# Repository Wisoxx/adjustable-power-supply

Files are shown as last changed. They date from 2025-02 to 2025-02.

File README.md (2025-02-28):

# Adjustable Laboratory Power Supply

## Device Overview  
This project focuses on designing and building a laboratory power supply with adjustable output voltage and integrated measurement of both voltage and load current. The device serves as a versatile tool for powering and diagnosing various electronic circuits. Special attention was given to precise voltage regulation, accurate measurements, and stable operation.
s

## Specifications
- **Input Voltage:** 230V AC, 50Hz  
- **Output Voltage Range:** 1.3V – 15V  
- **Maximum Output Current:** 0.5A  
- **Current Measurement Resolution:** 1mA  
- **Control:** Voltage adjustment and parameter reading via computer  
- **Voltage Regulation:** Manual, using a potentiometer  
- **Display:** Voltage measurement shown on a screen  

## Hardware Overview
The circuit consists of multiple sections:
1. **Power Supply and Rectification**  
2. **Microcontroller and User Interface**  
3. **Voltage Level Adjustment**  
4. **Voltage Transmission**  
5. **Voltage Measurement and Noise Suppression**  
6. **Current Measurement via a Series Resistor**

A schematic of the circuit is included in the documentation.

## Circuit Description
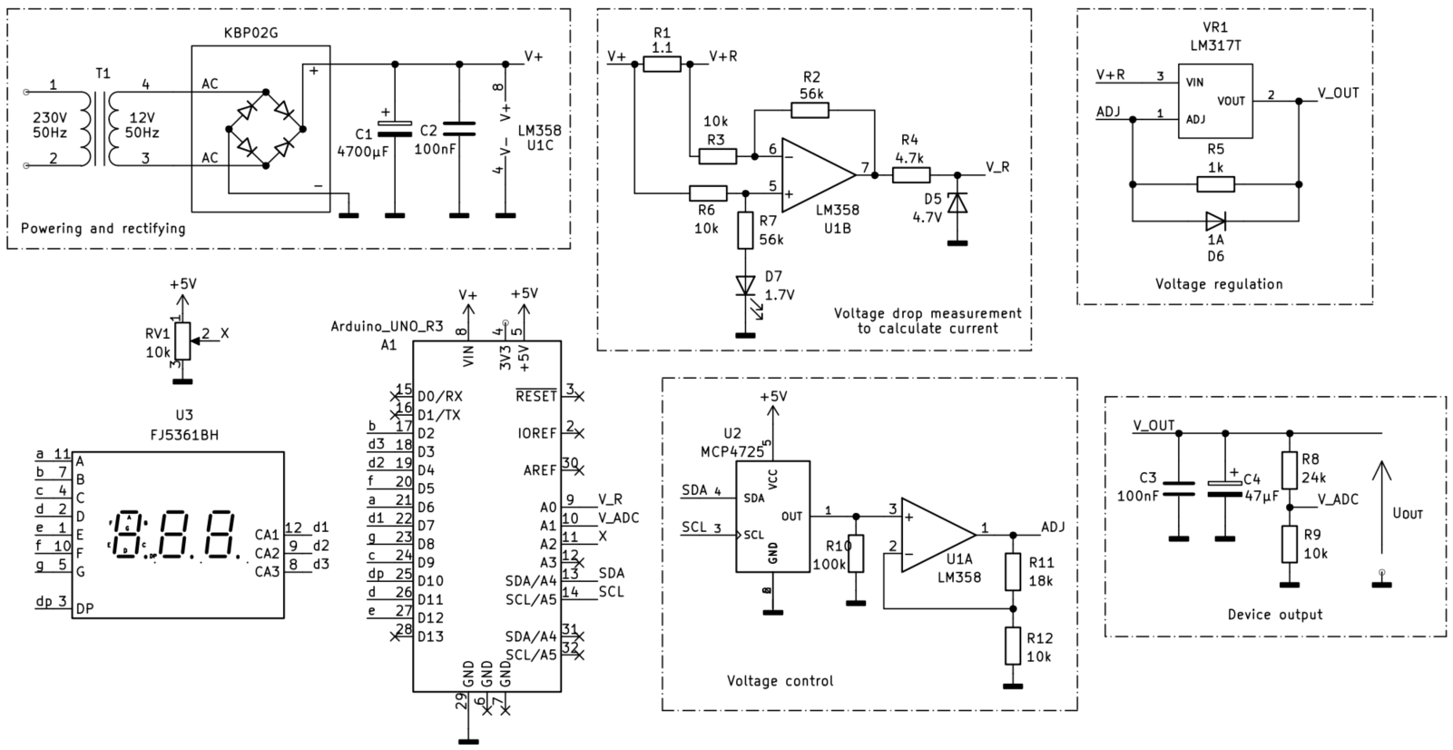
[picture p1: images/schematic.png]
Cicuit Schematic

The power supply uses a **230V to 12V transformer**, followed by a **KBP02G bridge rectifier** for full-wave rectification. A **4700µF capacitor (C1)** smooths voltage fluctuations, and **C2** acts as a decoupling capacitor. The supply voltage powers an **LM358 operational amplifier**, an **Arduino Uno microcontroller**, and other circuit components. 

Voltage regulation is performed using an **LM317T adjustable voltage regulator**, with control signals processed by the microcontroller. A **DAC (Digital-to-Analog Converter)** controlled via **I2C** is used to set the output voltage. A **non-inverting operational amplifier** scales the DAC output to drive the **LM317T**, enabling software-based voltage adjustment.

For **current measurement**, a **series resistor (R1)** is used to determine voltage drop, which is then amplified using a **differential amplifier**. The microcontroller calculates the current using Ohm's Law.

User interaction is facilitated through a **potentiometer (RV1)** for manual voltage adjustment and a **three-digit 7-segment display** for real-time parameter visualization.

## Software Implementation
The Arduino Uno is programmed using **C++** in **Arduino IDE**. The software consists of two main modules:
1. **Main Module:** Reads voltage and current values, processes signals, and communicates with the computer.
2. **Display Module:** Handles the 7-segment display, efficiently updating digits to minimize memory usage.

The software also includes an optional feature to generate **sinusoidal waveforms**, which can be activated by modifying specific code sections.

## Device Views
Below are different perspectives of the assembled device:

### Front View
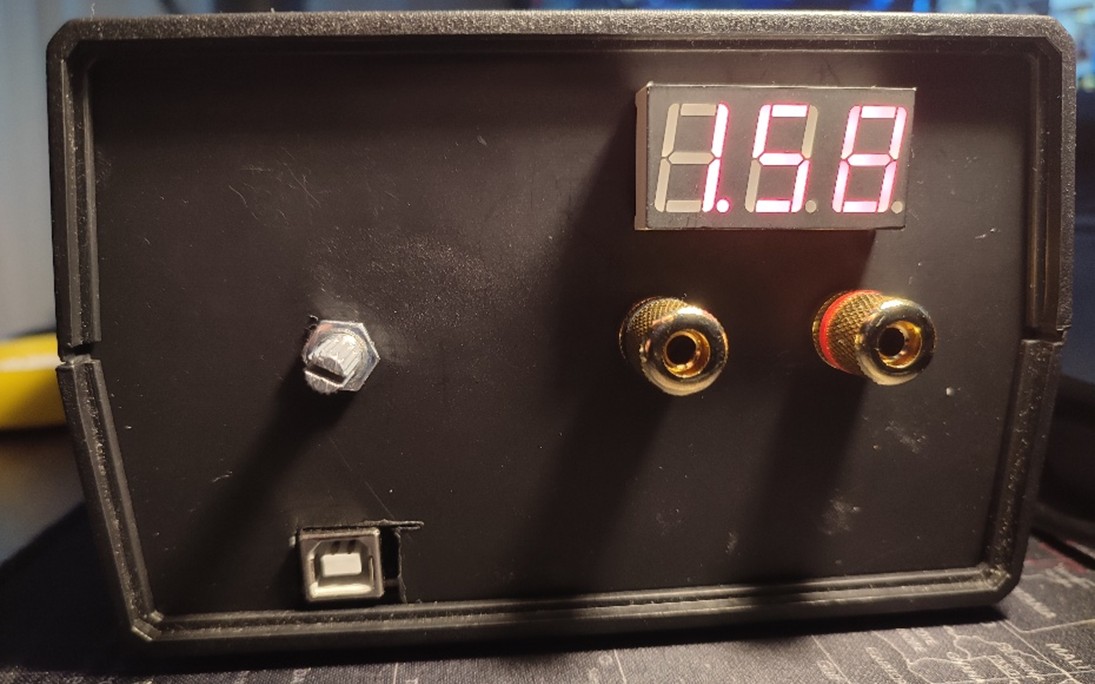
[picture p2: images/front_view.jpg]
Front View


### Back View
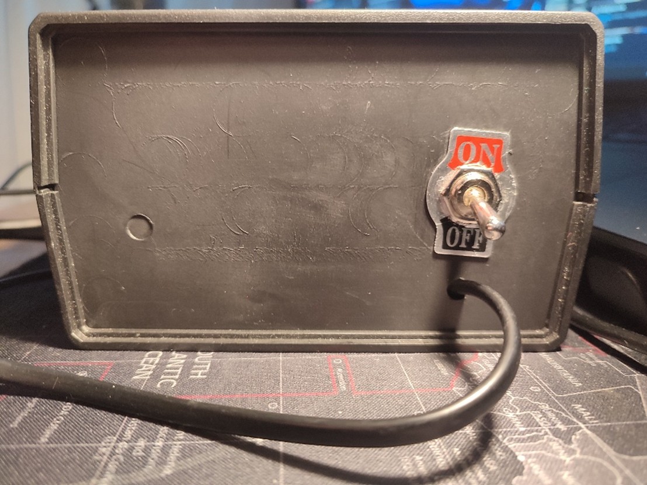
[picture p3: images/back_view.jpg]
Back View


### Internal Components
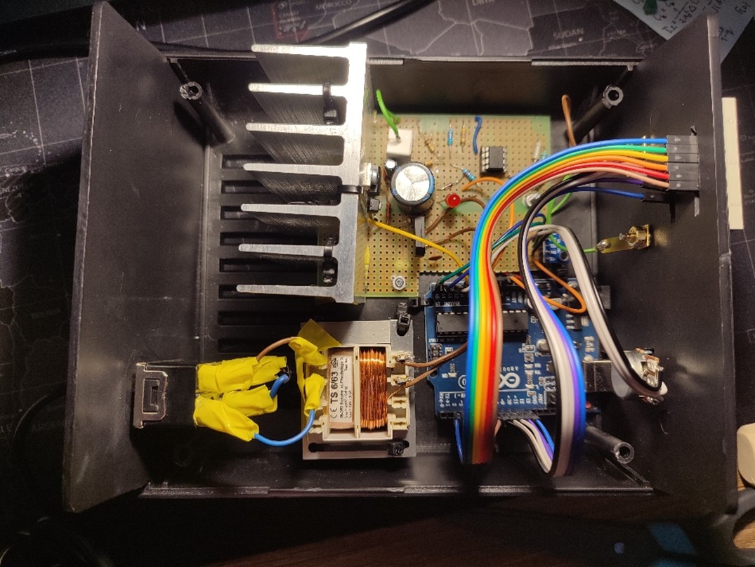
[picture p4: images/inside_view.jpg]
Inside View


### Internal Components
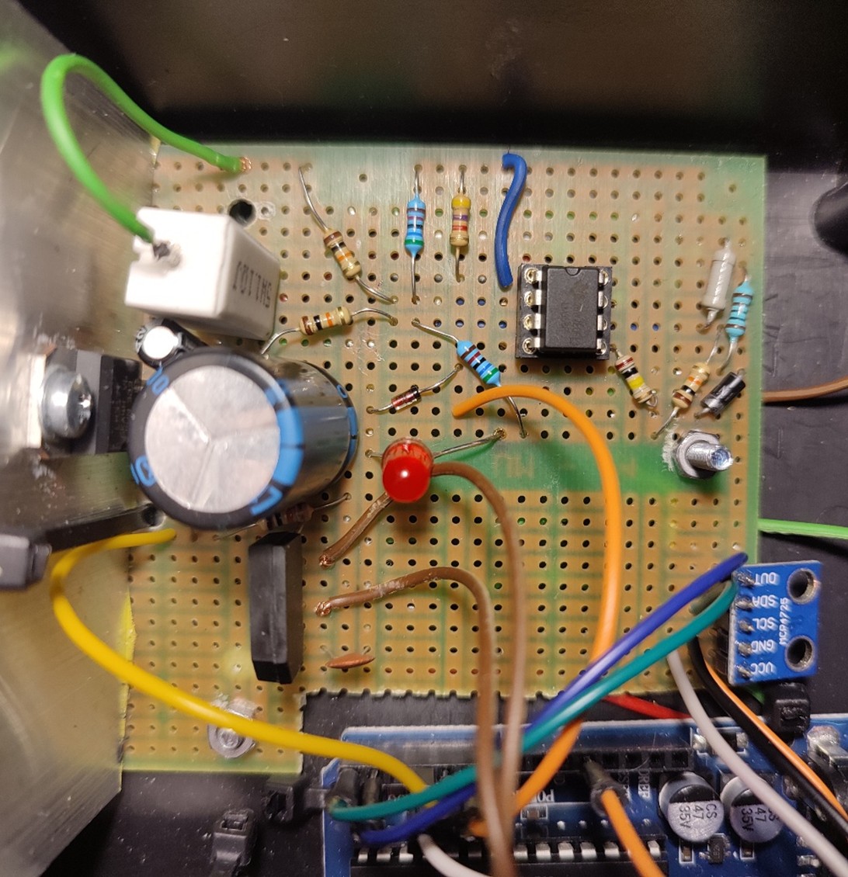
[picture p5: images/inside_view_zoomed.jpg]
Inside View Zoomed


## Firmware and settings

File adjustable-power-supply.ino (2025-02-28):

#include <Wire.h>//Include the Wire library to talk I2C
#include "display.h"
#include <math.h>

//This is the I2C Address of the MCP4725, by default (A0 pulled to GND).
#define MCP4725_ADDR 0x60
//For devices with A0 pulled HIGH, use 0x60
const int i_pin = A0;
const int u_pin = A1;
const int x_pin = A2;
const int size = 100;

int sineWave[size];
int x;
int index = 0;
unsigned long lastSerialUpdate = 0;
const int serialUpdateInterval = 100;
int sample_idx = 0;

void generateSineWave() {
  for (int i = 0; i < size; i++) {
    float angle = (2.0 * M_PI * i) / size; // Convert index to angle
    float sineValue = (sin(angle) + 1.0) / 2.0;  // Normalize from -1..1 to 0..1
    sineWave[i] = (int)(sineValue * 4095); // Scale to 12-bit DAC range (0-4095)
  }
}

void setup()
{
  setupDisplay();
  Wire.begin();
  Serial.begin(115200);
  generateSineWave();
};

void loop()
{
  loopDisplay();
  // displayFloat(12.3);
  if (millis() - lastSerialUpdate >= serialUpdateInterval) {
      lastSerialUpdate = millis();

    // Read ADC values
    int raw_x = analogRead(x_pin);
    int raw_voltage = analogRead(u_pin);
    int raw_current = analogRead(i_pin);

    // Convert to real voltage (assuming 5V reference and 10-bit ADC)
    float u = raw_voltage * (5.0 / 1023.0) * 3.517;
    float i_scaled = raw_current * (5.0 / 1023.0);  // voltage on resistor 1.1 ohm and minus offset
    float i = 0.0347 * i_scaled * i_scaled * i_scaled - 0.227 * i_scaled * i_scaled + 0.6511 * i_scaled - 0.6063;  // aproximation
    i = i < 0 ? 0 : i;

    // float x_scaled = map(raw_x, 0, 1023, 0, 4095) * (sineWave[index] / 4095.0);
    // x = (int)x_scaled;  // Convert back to integer
    x = map(raw_x, 0, 1023, 0, 4095);

    // Ensure x is within bounds
    x = constrain(x, 0, 4095);

    Serial.print("X:");
    Serial.print(map(x, 0, 4095, 127, 1535)/100.0);
    Serial.print("V, ");

    Serial.print("U:");
    Serial.print(u, 2);
    Serial.print("V, ");
    displayFloat(u);

    Serial.print("I:");
    Serial.print(i, 3);
    Serial.println("A");


    Wire.beginTransmission(MCP4725_ADDR);
    Wire.write(64);                     // cmd to update the DAC
    Wire.write(x >> 4);        // the 8 most significant bits...
    Wire.write((x & 15) << 4); // the 4 least significant bits...
    Wire.endTransmission();
    // index = (index + 1) % size;
  }
}

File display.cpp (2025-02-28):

#include "display.h"

// Define segment pins
const int a = 6;
const int b = 2;
const int c = 9;
const int d = 11;
const int e = 12;
const int f = 5;
const int g = 8;
const int dp = 10;

// Define digit control pins (common anode)
const int digit1 = 7;
const int digit2 = 4;
const int digit3 = 3;

const int segments[] = {a, b, c, d, e, f, g, dp};
const int digits[] = {digit1, digit2, digit3};

// Segment patterns for numbers 0-9 (Common Anode: LOW = ON, HIGH = OFF)
const byte numbers[10][8] = {
  {0, 0, 0, 0, 0, 0, 1, 1}, // 0
  {1, 0, 0, 1, 1, 1, 1, 1}, // 1
  {0, 0, 1, 0, 0, 1, 0, 1}, // 2
  {0, 0, 0, 0, 1, 1, 0, 1}, // 3
  {1, 0, 0, 1, 1, 0, 0, 1}, // 4
  {0, 1, 0, 0, 1, 0, 0, 1}, // 5
  {0, 1, 0, 0, 0, 0, 0, 1}, // 6
  {0, 0, 0, 1, 1, 1, 1, 1}, // 7
  {0, 0, 0, 0, 0, 0, 0, 1}, // 8
  {0, 0, 0, 0, 1, 0, 0, 1}  // 9
};

// Array to store the numbers for each digit
int displayedNumbers[3] = {-1, -1, -1}; // Default to blank
bool displayedDots[3] = {false, false, false}; // Default no dots

unsigned long lastDisplayUpdate = 0;
const int displayUpdateInterval = 2;
int currentDigit = 0;

void setupDisplay() {
  for (int i = 0; i < 8; i++) {
    pinMode(segments[i], OUTPUT);
  }

  for (int i = 0; i < 3; i++) {
    pinMode(digits[i], OUTPUT);
    digitalWrite(digits[i], LOW);
  }
}

void loopDisplay() {
  if (millis() - lastDisplayUpdate >= displayUpdateInterval) {
      lastDisplayUpdate = millis();
      multiplexDisplay();
  }

  // Timer loop counting up with 2 decimal places
  // static float timer = 0.00; // Initial timer value
  // static unsigned long lastMillis = 0;

  // // Update timer every 10ms
  // if (millis() - lastMillis >= 100) {
  //   lastMillis = millis(); // Reset the timer
  //   timer += 0.1;          // Increment timer by 0.01s

  //   if (timer >= 100.00) {
  //       timer = 0.00;  // Reset after 100 seconds
  //   }

  //   displayFloat(timer); // Display the updated timer
  // }
  // setDigitActive(0);
  // setDigitActive(1);
  // setDigitActive(2);
  // setDigit(0, false);
  // displayFloat(12.3);
}

void multiplexDisplay() {
  setDigitInactive(currentDigit);  // turn off previous digit
  currentDigit = (currentDigit + 1) % 3;  // switch to current digit
  setDigit(displayedNumbers[currentDigit], displayedDots[currentDigit]);
  setDigitActive(currentDigit);
}

void setDigitActive(int digitIndex){
  if (digitIndex < 0 || digitIndex > 2) return;

  digitalWrite(digits[digitIndex], HIGH);
}

void setDigitInactive(int digitIndex){
  if (digitIndex < 0 || digitIndex > 2) return;

  digitalWrite(digits[digitIndex], LOW);
}

void setDigit(int number, bool dot) {
  if (number == -1) {
    for (int i = 0; i < 7; i++) {
      digitalWrite(segments[i], HIGH);
    }
  } else {
    for (int i = 0; i < 7; i++) {
      digitalWrite(segments[i], numbers[number][i]);
    }
  }

  digitalWrite(dp, dot ? LOW : HIGH);
}

void displayFloat(float value) {
  int firstDigit, secondDigit, thirdDigit;
  bool decimalPoints[3] = {false, false, false};

  // Cap value at 999
  if (value > 999) value = 999;

  if (value >= 100) {
    firstDigit = (int)value / 100;
    secondDigit = ((int)value / 10) % 10;
    thirdDigit = (int)value % 10;
  } 
  else if (value >= 10) {
    firstDigit = (int)value / 10;
    secondDigit = (int)value % 10;
    thirdDigit = (int)(value * 10) % 10;
    decimalPoints[1] = true;
  } 
  else if (value >= 1) {
    firstDigit = (int)value;
    secondDigit = (int)(value * 10) % 10;
    thirdDigit = (int)(value * 100) % 10;
    decimalPoints[0] = true;
  } 
  else {
    firstDigit = 0;
    secondDigit = (int)(value * 10) % 10;
    thirdDigit = (int)(value * 100) % 10;
    decimalPoints[0] = true;
  }

  displayedNumbers[0] = firstDigit;
  displayedNumbers[1] = secondDigit;
  displayedNumbers[2] = thirdDigit;

  displayedDots[0] = decimalPoints[0];
  displayedDots[1] = decimalPoints[1];
  displayedDots[2] = decimalPoints[2];
}
